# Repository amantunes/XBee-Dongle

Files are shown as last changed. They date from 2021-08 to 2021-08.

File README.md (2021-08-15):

# XBee Dongle

This small USB-C dongle was developed with the objective of obtaining long range, relatively low bitrate communication with a rover or drone, as a way to transmit telemetry data to a computer or smartphone.

For this, a CP2102N USB-to-UART bridge was used. This bridge provides a small internal 100 mA 3.3V voltage regulator, which is used to power a Digi XBee 2.4 GHz communications module with an integrated chip antenna.

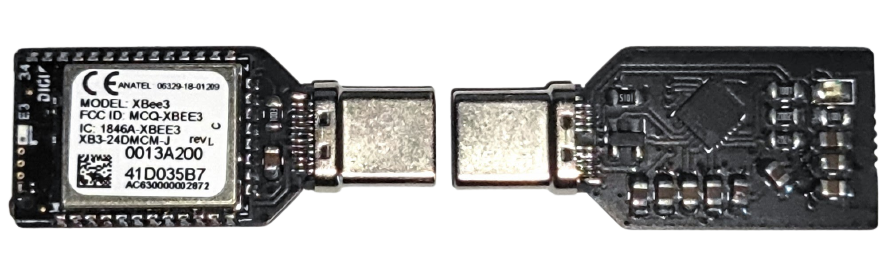
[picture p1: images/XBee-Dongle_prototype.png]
Xbee-Dongle Prototype Image


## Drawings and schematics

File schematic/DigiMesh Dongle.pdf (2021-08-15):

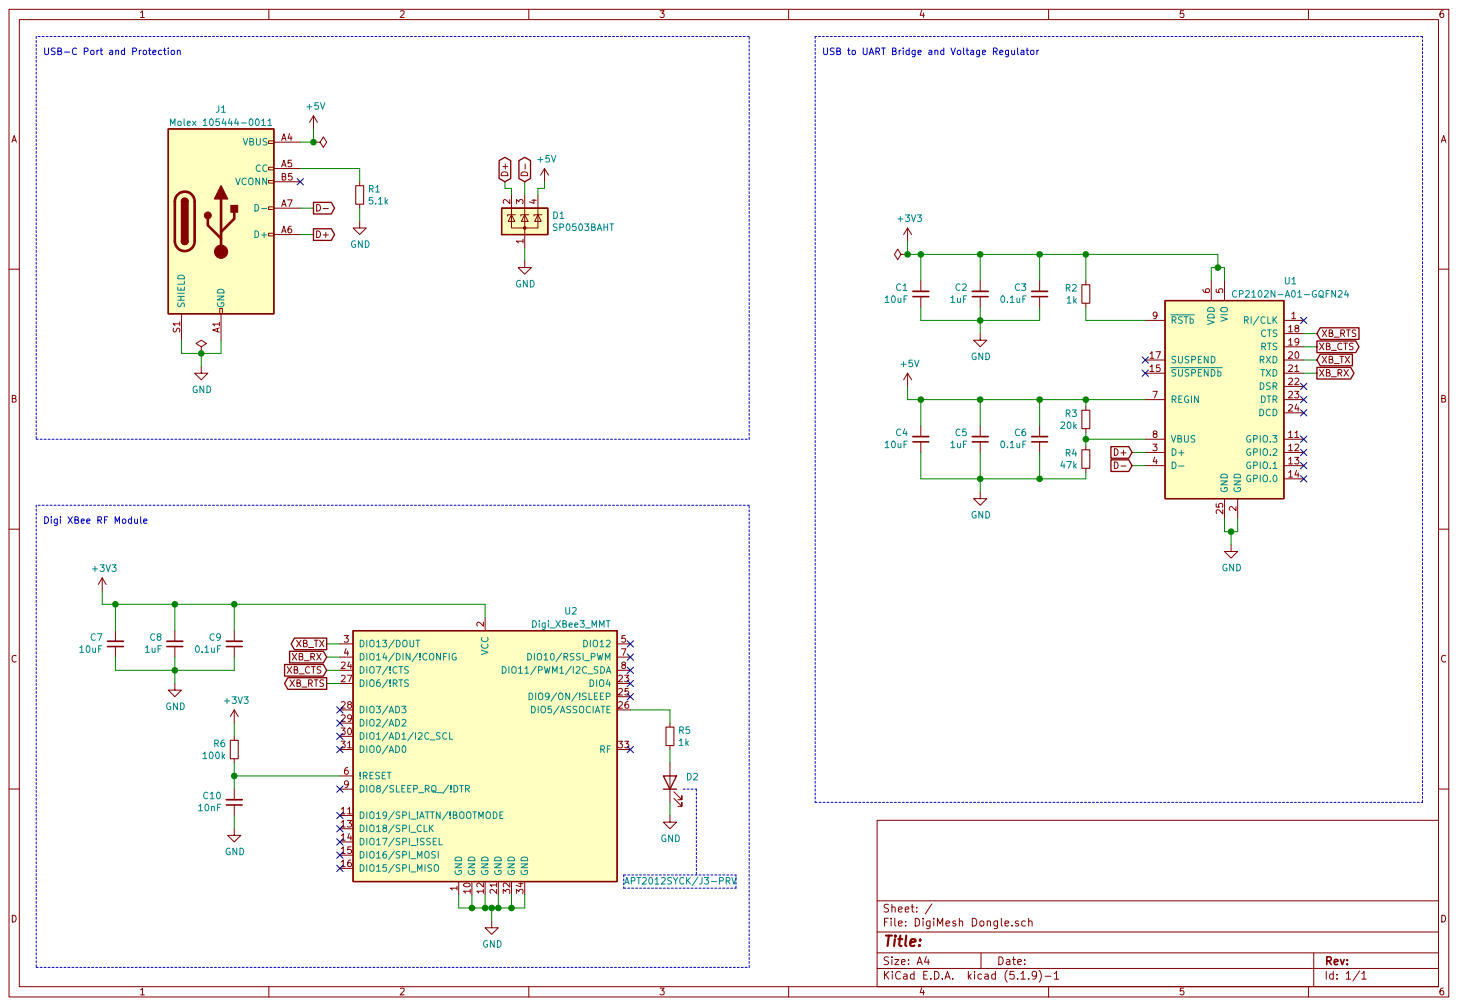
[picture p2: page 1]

6 REGIN 7 VBUS 8 RSTb 9 U1 CP2102N-A01-GQFN24 +3V3 +5V GND

D- Digi XBee RF Module

2 RXD 20 TXD 21 DSR 22 DTR 23 DCD 24 GND 25 D+ 3 D- 4 VIO

2 GND 21 DIO4 23 DIO7/!CTS 24 DIO9/ON/!SLEEP 25 DIO5/ASSOCIATE 26 DIO6/!RTS 27 DIO3/AD3 28 DIO2/AD2 29 DIO13/DOUT 3 DIO1/AD1/I2C_SCL 30 DIO0/AD0 31 GND 32 RF 33 GND 34 DIO14/DIN/!CONFIG 4 DIO12 5

1 GND 10 DIO19/SPI_!ATTN/!BOOTMODE 11 GND 12 DIO18/SPI_CLK 13 DIO17/SPI_!SSEL 14 DIO16/SPI_MOSI 15 DIO15/SPI_MISO 16 VCC

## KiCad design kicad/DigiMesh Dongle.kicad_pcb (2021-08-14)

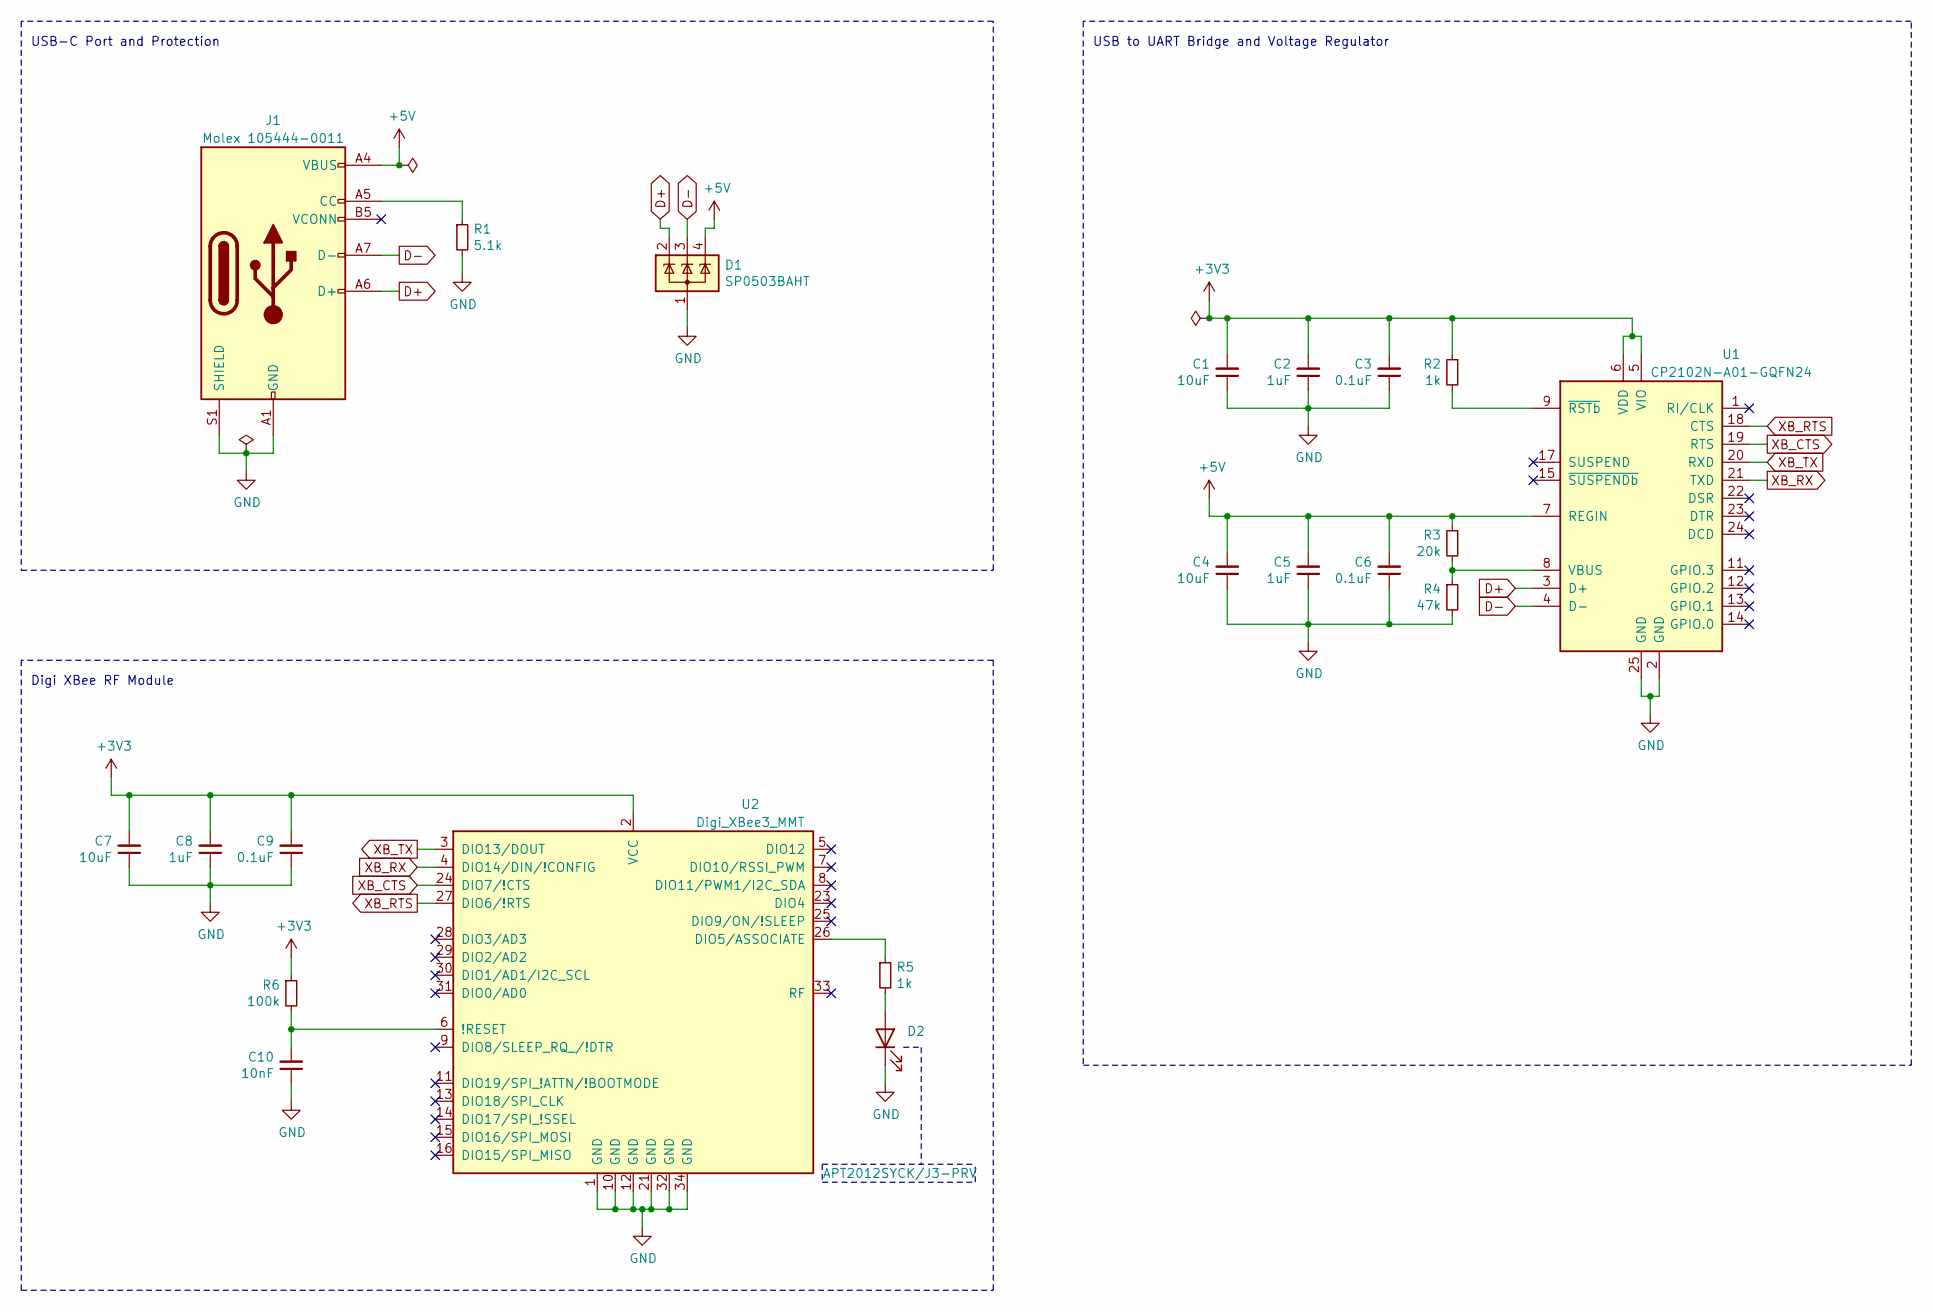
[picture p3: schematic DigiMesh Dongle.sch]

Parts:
C1, C4, C7: 10uF; C_0805_2012Metric_Pad1.18x1.45mm_HandSolder
C2, C5, C8: 1uF; C_0805_2012Metric_Pad1.18x1.45mm_HandSolder
C3, C6, C9: 0.1uF; C_0805_2012Metric_Pad1.18x1.45mm_HandSolder
C10: 10nF; C_0805_2012Metric_Pad1.18x1.45mm_HandSolder
D1: SP0503BAHT; SOT-143
D2: APT2012SYCK/J3-PRV; LED_0805_2012Metric_Pad1.15x1.40mm_HandSolder
J1: Molex 105444-0011; USB_C_Plug_Molex_105444
R1: 5.1k; R_0805_2012Metric_Pad1.20x1.40mm_HandSolder
R2, R5: 1k; R_0805_2012Metric_Pad1.20x1.40mm_HandSolder
R3: 20k; R_0805_2012Metric_Pad1.20x1.40mm_HandSolder
R4: 47k; R_0805_2012Metric_Pad1.20x1.40mm_HandSolder
R6: 100k; R_0805_2012Metric_Pad1.20x1.40mm_HandSolder
U1: CP2102N-A01-GQFN24; QFN-24-1EP_4x4mm_P0.5mm_EP2.6x2.6mm
U2: Digi_XBee3_MMT; Module_XCVR_XB3-24Z8CM-J

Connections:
+3V3: C1.2, C2.2, C3.2, C7.2, C8.2, C9.2, R2.1, R6.1, U1.5 (VIO), U1.6 (VDD), U2.2 (VCC)
+5V: C4.2, C5.2, C6.2, D1.4 (K), J1.A4 (VBUS), J1.A9 (VBUS), J1.B4 (VBUS), J1.B9 (VBUS), R3.1, U1.7 (REGIN)
D+: D1.2 (K), J1.A6 (D+), U1.3 (D+)
D-: D1.3 (K), J1.A7 (D-), U1.4 (D-)
GND: C1.1, C2.1, C3.1, C4.1, C5.1, C6.1, C7.1, C8.1, C9.1, C10.1, D1.1 (A), D2.1 (K), J1.A1 (GND), J1.A12 (GND), J1.B1 (GND), J1.B12 (GND), J1.S1 (SHIELD), R1.2, R4.2, U1.2 (GND), U1.25 (GND), U2.1 (GND), U2.10 (GND), U2.12 (GND), U2.21 (GND), U2.32 (GND), U2.34 (GND)
unnamed: C10.2, R6.2, U2.6 (!RESET)
unnamed: D2.2 (A), R5.2
unnamed: J1.A5 (CC), R1.1
unnamed: R2.2, U1.9 (~RSTb)
unnamed: R3.2, R4.1, U1.8 (VBUS)
unnamed: R5.1, U2.26 (DIO5/ASSOCIATE)
XB_CTS: U1.19 (RTS), U2.24 (DIO7/!CTS)
XB_RTS: U1.18 (CTS), U2.27 (DIO6/!RTS)
XB_RX: U1.21 (TXD), U2.4 (DIO14/DIN/!CONFIG)
XB_TX: U1.20 (RXD), U2.3 (DIO13/DOUT)

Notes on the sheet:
USB-C Port and Protection
USB to UART Bridge and Voltage Regulator
Digi XBee RF Module

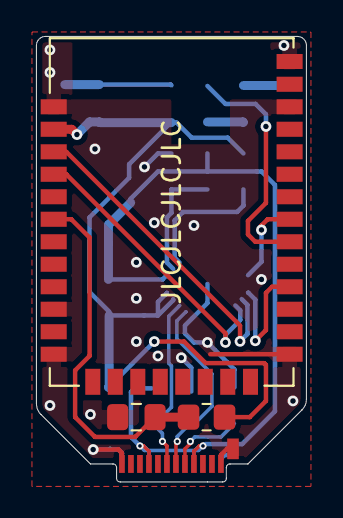
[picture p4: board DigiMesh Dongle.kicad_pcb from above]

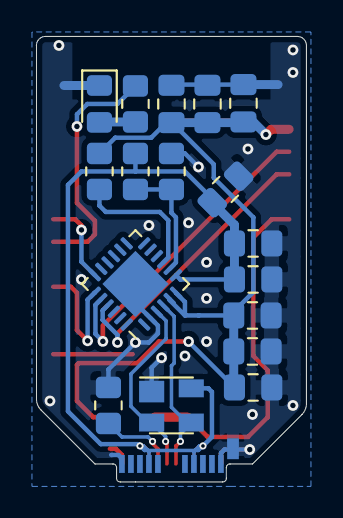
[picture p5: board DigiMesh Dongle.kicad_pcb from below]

Board: 2 copper layers, 15.0 x 24.8 mm, 21 parts (17 on the bottom side), 15 nets.
